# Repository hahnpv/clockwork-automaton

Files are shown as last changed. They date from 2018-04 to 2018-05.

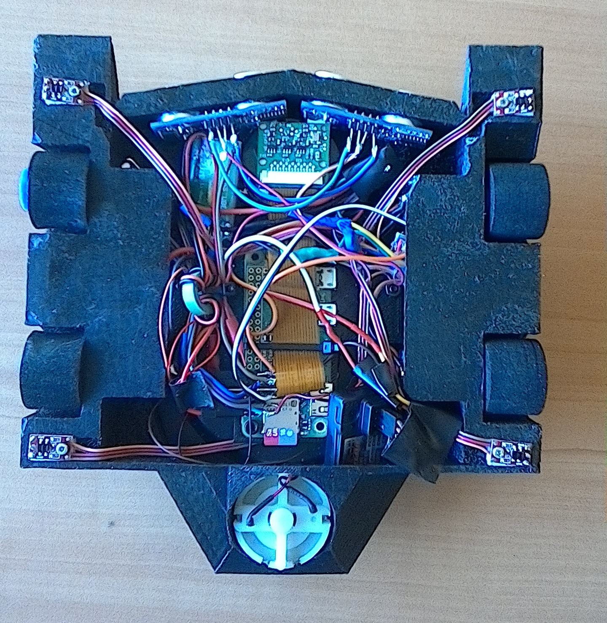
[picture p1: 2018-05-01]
geometry/clockwork-automaton-bottom.jpg

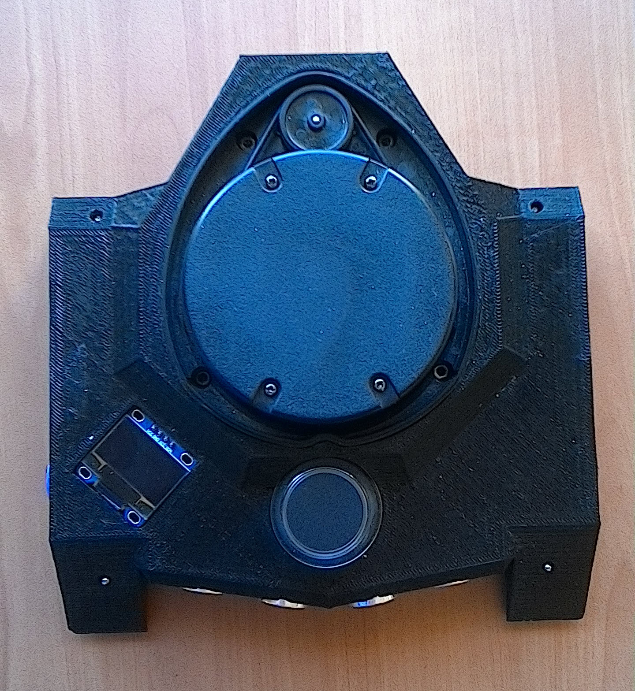
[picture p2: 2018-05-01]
geometry/clockwork-automaton-top.jpg

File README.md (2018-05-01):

This repository contains the code used for the 1lb autonomous robot CLOCKWORK AUTOMOTON at Robogames 2018. This is my first autonomous combat robot entry and was designed to "not suck" but mostly to collect LIDAR and video to post-process and come up with a better concept for next year.

(fuller story: I've been a bit of a road warrior this spring, traveling for work leading up to the day of Robogames. I printed a test platform earlier in the year to test concepts to downselect, but ran out of time and used the test platform as my bot)

The robot I built has a XV-11 LIDAR module and a Raspberry Pi Zero W with a camera. The camera has a 360 degree lense, partially occluded aft by the LIDAR module. The initial concept was a very simple LIDAR algorithm based on the assumed battle box: a 6'x6' box with a sumo ring or square (3' diameter circle  or 2'x4' rectangle). The LIDAR would then look at returns between zero and a foot and navigate in the direction with the most returns - any returns over a foot in the latter case might be the walls.

Unfortunately the day before Robogames I discovered that the 2'x4' rectangle had push-outs: polycarbonate walls with holes to push out another bot. This messes up the LIDAR algorithm because clean polycarbonate should allow LIDAR to pass through but oblique hits and scuffed up polycarb would give scattered returns. I could no longer trust the nearest returns to be the opposing bot. So, I ditched the algorithm and just record data for future use.

The architecture is a Arduino which reads reflectance sensors on the bottom corners of the bot and drives the motors. The default algorithm is very simple:
- Go forward
- If front left reflectance sensor senses edge, latch left motor in reverse
- If front right reflectance sensor senses edge, latch right motor in reverse
- If front left reflectance sensor senses edge, latch left motor forward
- If front right reflectance sensor senses edge, latch right motor forward

It would also receive i2c heading commands from the Pi (disabled this time around) 

I competed against four other competitors (round robin) and got third place (out of 5). I won 2 matches and lost the other two.

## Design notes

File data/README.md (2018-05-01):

The .h264 files are the native output from the Raspberry Pi. They can be converted into MP4 files by using ffmpeg - check out the /analysis/ folder for an example of how this is done.

The LIDAR spins at approximately 5 revolutions per second and should report 5 scans per second, unfortunately, this is not the case. I do not have an official diagnosis yet but there are two culprits
1) The LIDAR was not spinning at full speed, and only putting out intermittant results. This is probable, I was supplying 3V3 from the Pi and not checking RPM / using a PID voltage control
2) My script sucks

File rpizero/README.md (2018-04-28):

autonomy.py is started on boot by the autonomy script in /etc/init.d/

the /lidar/ folder contains a c++ implementation which reads LIDAR (not used)
the /old/ folder contains testing scripts and earlier implementations. Some are open source scripts from Adafruit etc. examples which were tweaked to test individual implementations.

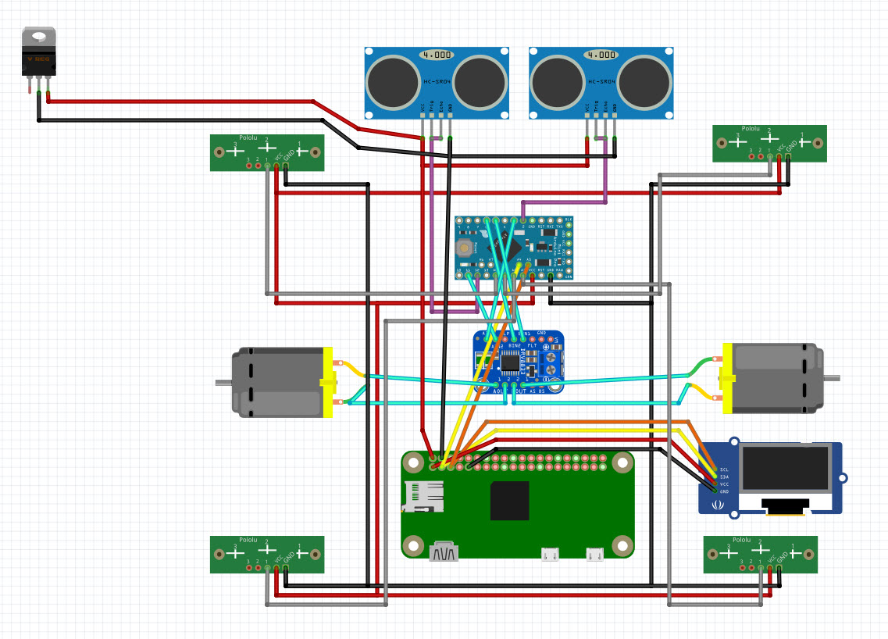
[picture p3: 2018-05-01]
geometry/clockwork-automaton.jpg

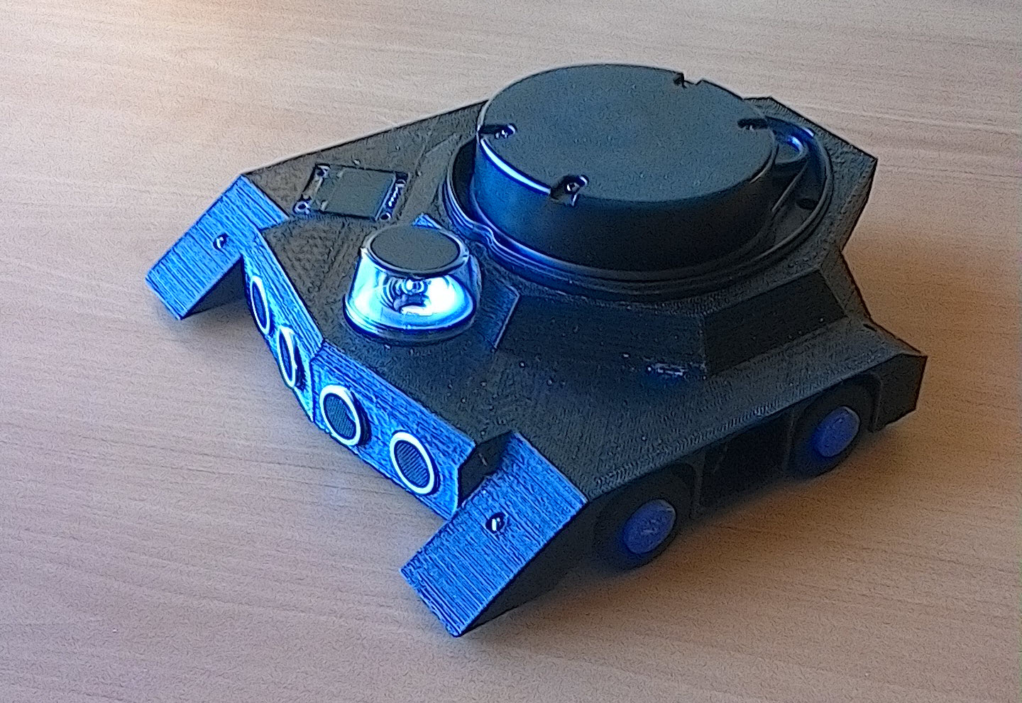
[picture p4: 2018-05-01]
geometry/clockwork-automaton-iso.jpg

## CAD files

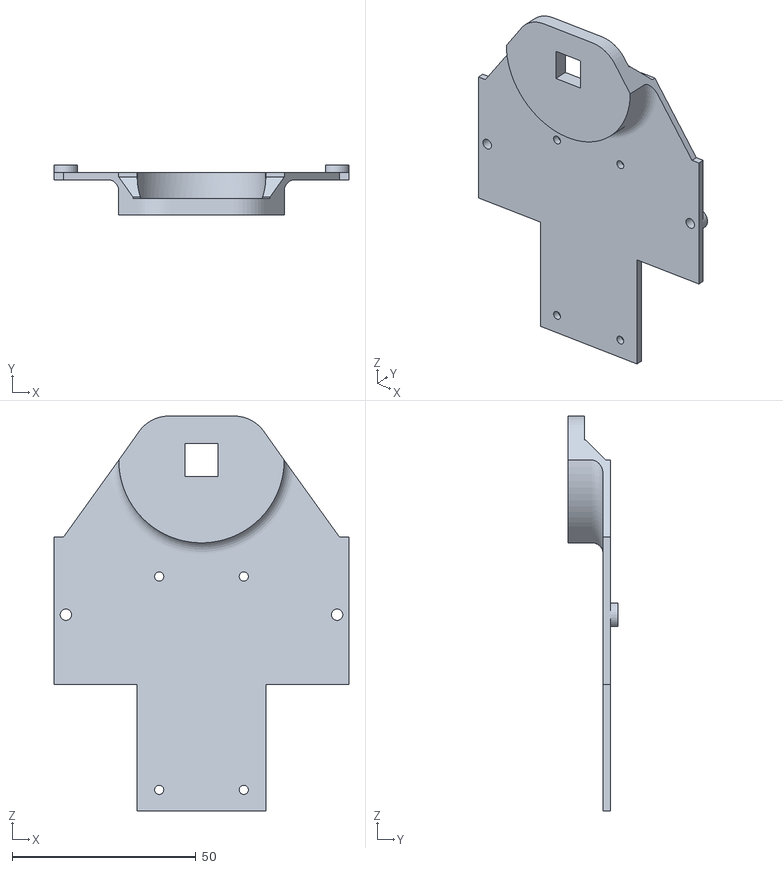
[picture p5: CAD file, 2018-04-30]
geometry/bottom_plate.stl
80.1 x 13.5 x 107.4

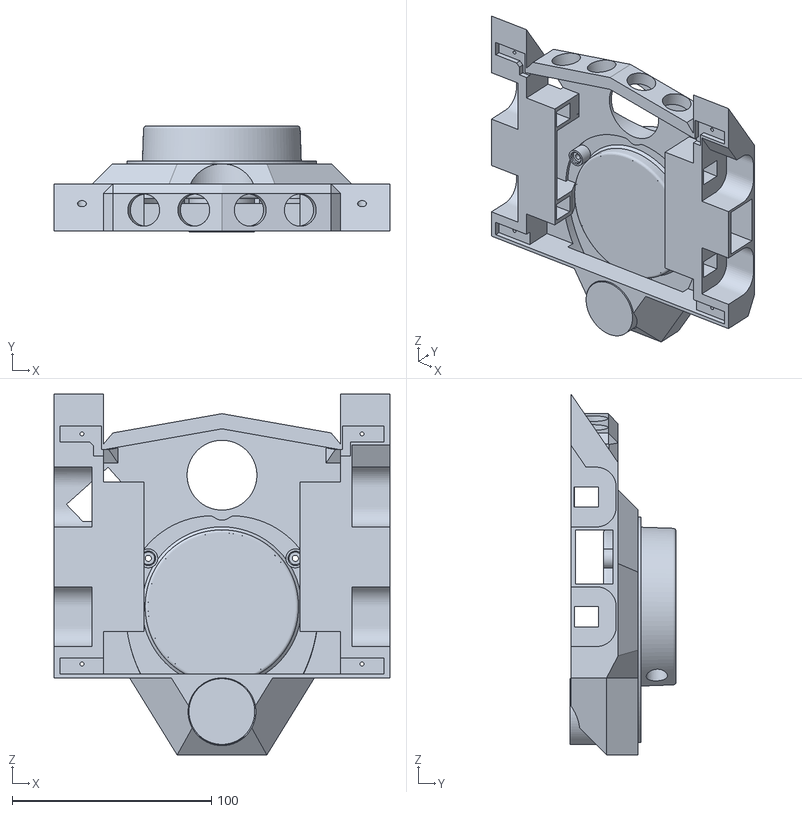
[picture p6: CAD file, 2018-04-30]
geometry/clockwork_automoton.stl
168.5 x 53.2 x 181.1

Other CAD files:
geometry/clockwork_automoton.f3d

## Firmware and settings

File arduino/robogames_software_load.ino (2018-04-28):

#include <Wire.h>
#include <EnableInterrupt.h>

#define SLAVE_ADDRESS 0xC4
volatile byte bam = 128;                       // BAM byte from LIDAR

#define ontime_duration 240                    // seconds until bot deactivates self due to runtime
#define radio_duration    2                    // seconds until bot deactivates self due to radio drop
unsigned long int deadtimer = 0.;              // seconds of ontime
bool dead = false;                             // if deadman > deadman_duration * 1000, true

#define rc_switch_pin_in 9                      // switch pin
volatile int rc_switch_pulsewidth_in = -100;    // inital dummy value
volatile long rc_switch_pulse_start;            // start of pulse
volatile unsigned long int rc_switch_time = 0.; // Timestamp of last interrupt to kill bot if radio dies

#define latch_out 7                             // latch pin output to rpi

bool motor = true;  // disable motor commands
bool debug = true; // disable serial output

////STARTING CONFIGURATION////////////////////////////////////////////////////
int incr =  75;              // bsae robot speed
int number = 90;             // flipper pos FIXME rename
int threshold = 150;         // reflectance threshold. 500 on old bot
int leftCmd = incr;
int rightCmd = incr;
////STARTING CONFIGURATION////////////////////////////////////////////////////

typedef struct Motor
{
  int pin1;
  int pin2;
};
Motor leftmotor  = {6, 5};
Motor rightmotor = {3,11};

byte sns[4];

int longestMillis = 0;
unsigned long int lastMillis;
unsigned long pingTimer1, pingTimer2;

void setup() {
  if(debug)  Serial.begin(115200);
    
  /// INITIALIZE RADIO ////////////////////////////////////////////////////
  pinMode(rc_switch_pin_in, INPUT);
  pinMode(latch_out, OUTPUT);
  enableInterrupt(rc_switch_pin_in, isrSwitchRising, RISING);

  /// CONFIGURE i2c ///////////////////////////////////////////////////////////
  Wire.begin(SLAVE_ADDRESS);
  Wire.onReceive(receiveData);
  if (debug) Serial.println("i2c ready!");
}

bool pause = false;

void loop() {
  sns[0] = analogRead(2) < threshold ? 1 : 0;
  sns[1] = analogRead(3) < threshold ? 1 : 0;
  sns[2] = analogRead(0) < threshold ? 1 : 0;
  sns[3] = analogRead(1) < threshold ? 1 : 0;

  if (debug)
  {
    int duration = millis()-lastMillis;
    lastMillis = millis();
    Serial.print(analogRead(2));Serial.print(" | ");Serial.print(analogRead(3));Serial.print(" | ");
    Serial.print(analogRead(0));Serial.print(" | ");Serial.print(analogRead(1));Serial.print(" | ");
    Serial.print(duration);Serial.print(" || ");Serial.print(pause); Serial.print(" || ");
    Serial.print(rc_switch_pulsewidth_in);;Serial.print(" || ");Serial.println(deadtimer);
  }

  if ( (rc_switch_pulsewidth_in > 1600) && !dead)
  {
    if(sns[0])
    {
      leftCmd = incr;
    }
    if(sns[1])
    {
      rightCmd = incr;
    }
    if(sns[2])
    {
      leftCmd = -incr;
    }
    if(sns[3])
    {
      rightCmd = -incr;
    }

    // ADD BAM STEERING

      // TODO mix in steering here -> do a +/- delta for left and right to do a harder turn?
      motorSpeed(leftmotor, leftCmd /*+ leftSteer*/);  
      motorSpeed(rightmotor, rightCmd /*+ rightSteer*/);
      digitalWrite(latch_out, HIGH);
  }
  else
  {
      // motors off 
      motorSpeed(leftmotor, 0);
      motorSpeed(rightmotor, 0);
      digitalWrite(latch_out, LOW);
      if (debug) Serial.println("DEAD");  
  }

  // CHECK IF YOU SHOULD START TIMING
  if (!dead && (rc_switch_pulsewidth_in > 1600) && deadtimer==0)
  {
    deadtimer = millis();
    if (debug) Serial.println("START TIMING");
  }

  /// CHECK IF YOU SHOULD BE DEAD
  if (!dead && (rc_switch_pulsewidth_in > 1600) && ((millis() - deadtimer) >= ontime_duration*1000UL))
  {
    dead = true;
    if (debug) Serial.println("SETTING DEADMAN");
  }  
  
  // CHECK IF YOU SHOULD RESET
  if (dead && (rc_switch_pulsewidth_in < 1400))
  {
      dead = false;
      deadtimer = 0;
      if (debug) Serial.println("RESETTING DEADMAN");  
  }

  // CHECK IF RADIO HAS DROPPED OUT
  if (!dead && (rc_switch_pulsewidth_in > 1600) && ((millis()-rc_switch_time) > radio_duration*1000))
  {
      rc_switch_pulsewidth_in = -100;
      if (debug) Serial.println("RADIO DISCONNECTED");
  }
}

void motorSpeed(Motor m, int cmd) {
  if (cmd < 0) {
    analogWrite(m.pin1, abs(cmd));
    digitalWrite(m.pin2, LOW);
  }
  else if (cmd > 0) {
    digitalWrite(m.pin1, LOW);
    analogWrite(m.pin2, cmd);
  }
  else {
    digitalWrite(m.pin1, LOW);
    digitalWrite(m.pin2, LOW);
  }
}

/// ISR for switch activation
void isrSwitchFalling() {
  rc_switch_pulsewidth_in = micros() - rc_switch_pulse_start;
  rc_switch_time = millis();
  disableInterrupt(rc_switch_pin_in);
  enableInterrupt(rc_switch_pin_in, isrSwitchRising, RISING);
}
void isrSwitchRising() {
  rc_switch_pulse_start = micros();
  disableInterrupt(rc_switch_pin_in);
  enableInterrupt(rc_switch_pin_in, isrSwitchFalling, FALLING);
}

// callback for received data
void receiveData(int byteCount){
  while(Wire.available())    // slave may send less than requested
  { 
    bam = Wire.read();
  }
}

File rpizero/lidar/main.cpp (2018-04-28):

#include <iostream>
#include <fstream>      // std::ifstream, std::ofstream
#include "SimpleSerial.h"
#include "LIDAR.h"

using namespace std;
using namespace boost;

int main(int argc, char* argv[])
{
    try {

        SimpleSerial serial("/dev/ttyAMA0",115200);
        //std::ifstream infile("frontroom.bin",std::ifstream::binary);

        std::ofstream outfile("capture.bin",std::ofstream::binary);
        std::ofstream outcsv("capture.csv", std::ofstream::binary);

        LIDAR LiDAR;
        for (int i = 0; i < 10000; i++) {
            unsigned char c = serial.readChar();
//            char c;
  //          infile.get(c);
            cout << "c = " << c << endl;
            if (LiDAR.isHeader(c)) {
                cout <<  "found header!" << endl;
                unsigned char packet[22];
                packet[0] = c;
                for (int j = 1; j <= 21; j++) {
                    packet[j] = serial.readChar();
  //                  infile.get(c);
    //                packet[j] = c;
                }
                PACKET p = LiDAR.readPacket(packet);
                cout << "Packet: " << p.point[1].angle << " " << p.speed << endl;
                
                  // write to outfile
                outfile.write (packet, 22); // size = # elements
                

		// NOTE: removing too much stuff causes serial to starve
                
                if (p.is_valid)
                for (int i = 0; i < 4; i++) {
                       outcsv << p.point[i].angle << ","<< p.point[i].r << "," 
                              << p.point[i].quality << "," << p.point[i].invalid << ","
                              << p.point[i].strength << endl;
                }

            }
        }

/*
	TODO
	0) impl memcpy in LiDAR
	2) implement boost program options (serial port, file, etc.)
	3) implement file input or serial input switch
	4) start working algorithms (look at boost geometry)
	5) tcp input? for wifi lidar roamer bot?
	6) look at part 6 of serial stream for making SimpleSerial look like iostream: http://www.webalice.it/fede.tft/serial_port/serial_port.html
compile w/ -lboost_system
*/
        outfile.close();
        outcsv.close();

    } catch(boost::system::system_error& e)
    {
        cout<<"Error: "<<e.what()<<endl;
        return 1;
    }
    
}

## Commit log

2018-04-30 adding robogames data and geometry files
    [bottom_plate.stl, clockwork_automoton.f3d, clockwork_automoton.stl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]
2018-04-30 adding lidar script
2018-05-01 adding fritzing
    [clockwork-automaton.fzz]
